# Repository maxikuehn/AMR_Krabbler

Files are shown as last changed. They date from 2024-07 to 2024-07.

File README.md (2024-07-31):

<div align="right">
HSMA Logo
</div>

<div align="center">

<h1>Technische Optimierungen am vierbeinigen Krabbler</h1>






<h3>Autonome Mobile Roboter - SS 2024</h3>
<h4>Maximilian Kühn</h4>

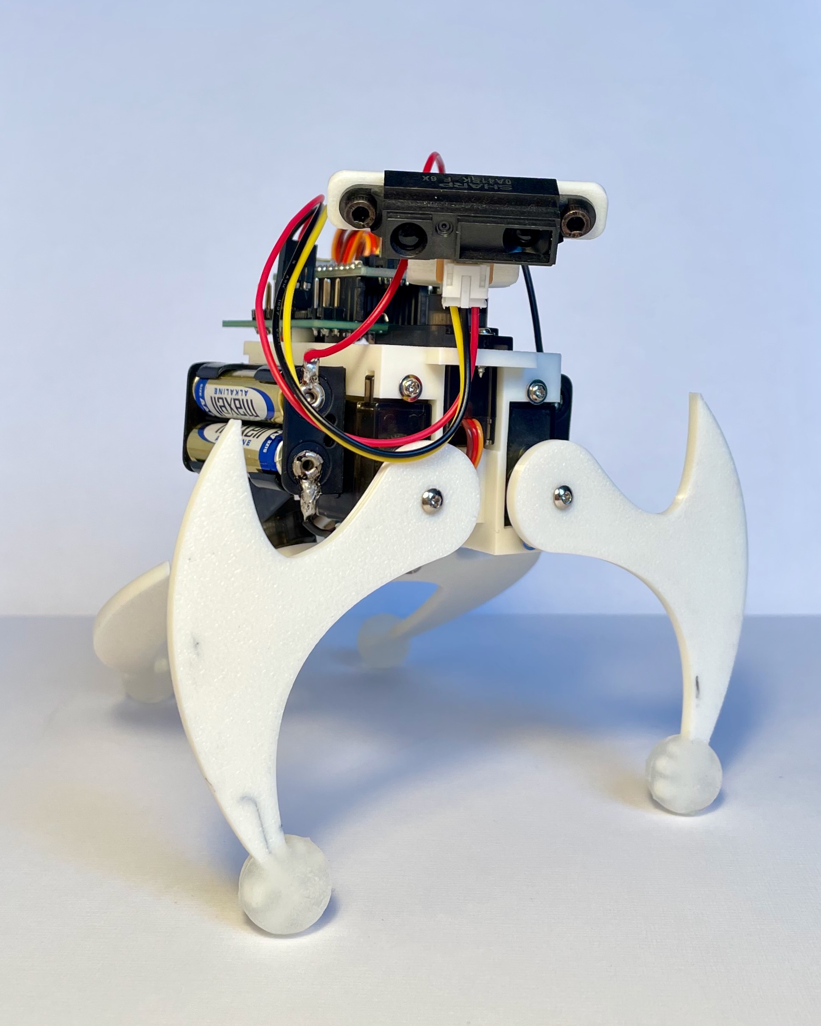
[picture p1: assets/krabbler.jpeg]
Krabbler


</div>

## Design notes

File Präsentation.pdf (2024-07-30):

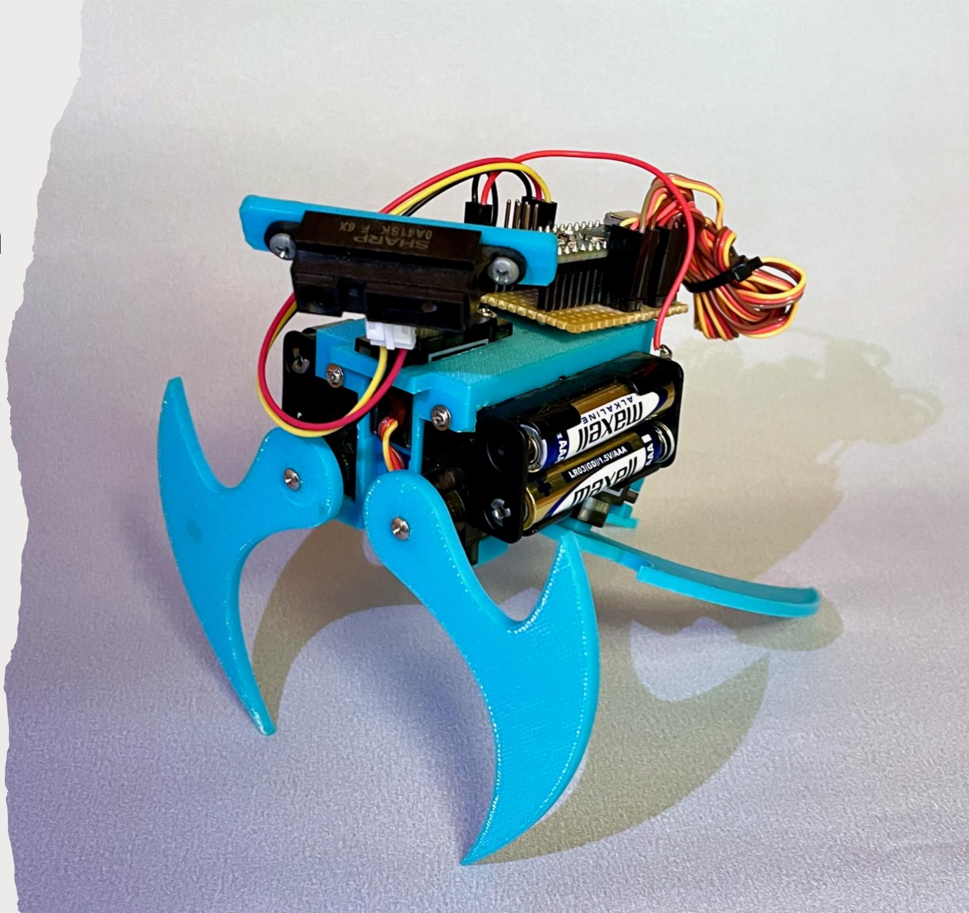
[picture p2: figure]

## Technische Optimierungen am vierbeinigen Krabbler

SS 24 – AMR
Maximilian Kühn

## Was ist der Krabbler

- simpler Roboter
- Arduino Nano
- 5 Servos
- Infrarotsensor
- Batterieversorgung
- 3D-Druck für die Teile

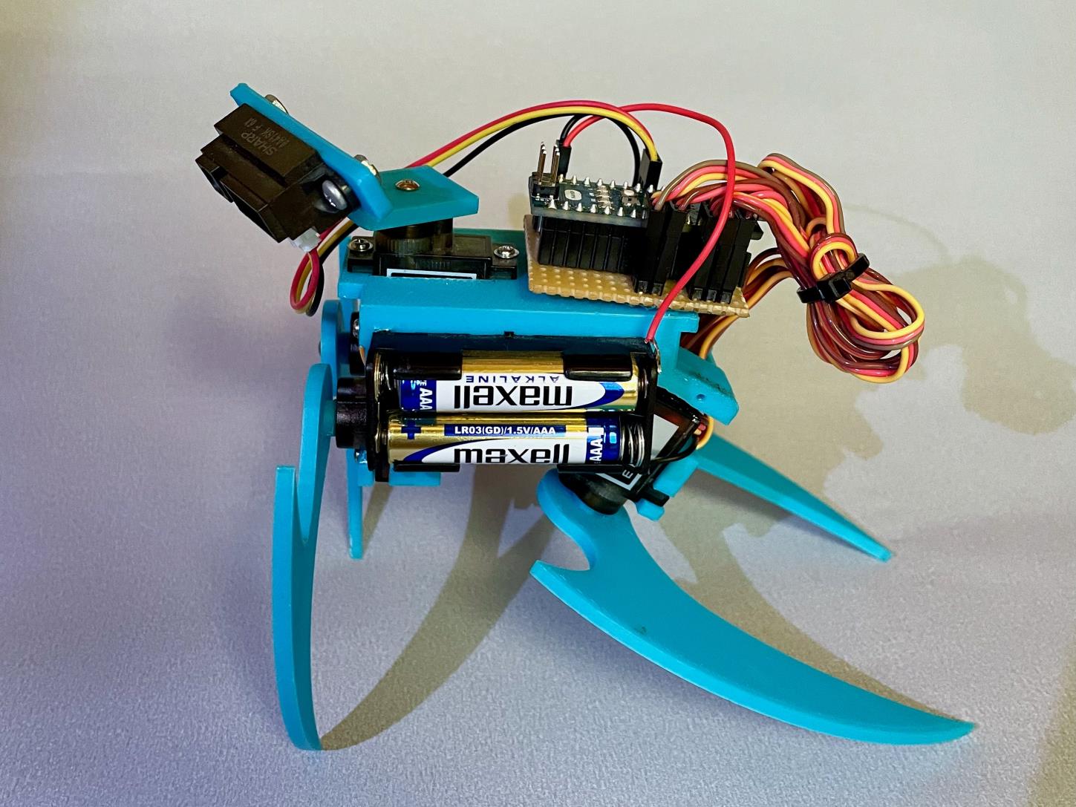
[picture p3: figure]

24.07.24 | Maximilian Kühn | 2

## Was ist an der Hardware nicht ideal?

- Platine
- Füße rutschen auf dem Tisch
- keine Möglichkeit ihn
auszuschalten
- 3D-Modelle nicht optimal

Version 2

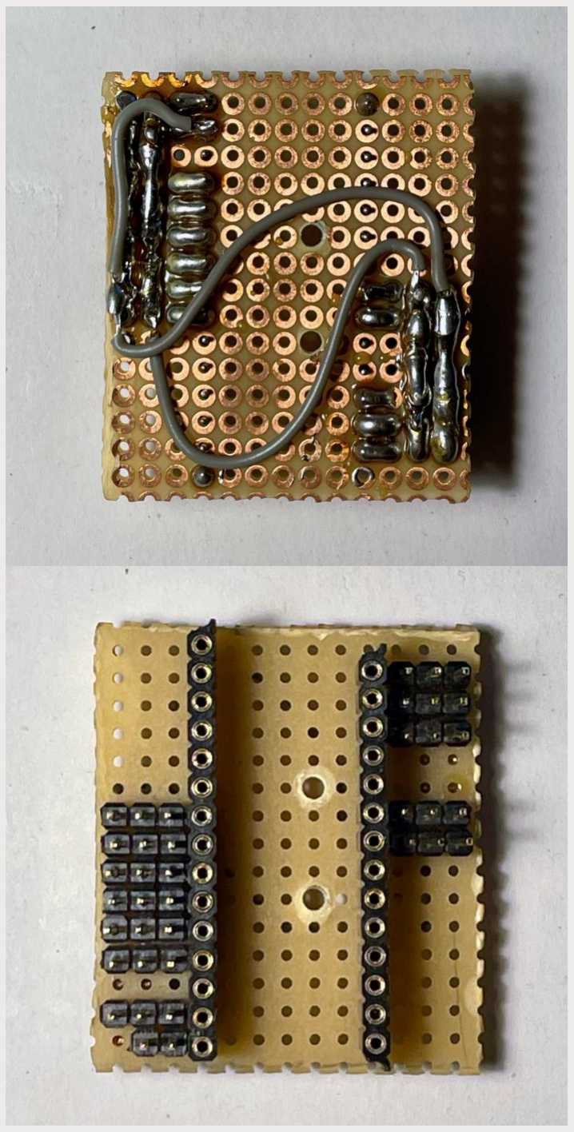
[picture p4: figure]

## Leiterplatte Version 1

alles von Hand gelötet
großer Zeitaufwand
fehleranfällig beim Löten
nicht intuitiv verwendbar

Version 2
✅ Unterstützung beim Löten ✅ intuitiv verwendbar
✅ kleiner Zeitaufwand

## Leiterplatte Version 2 Schaltplan

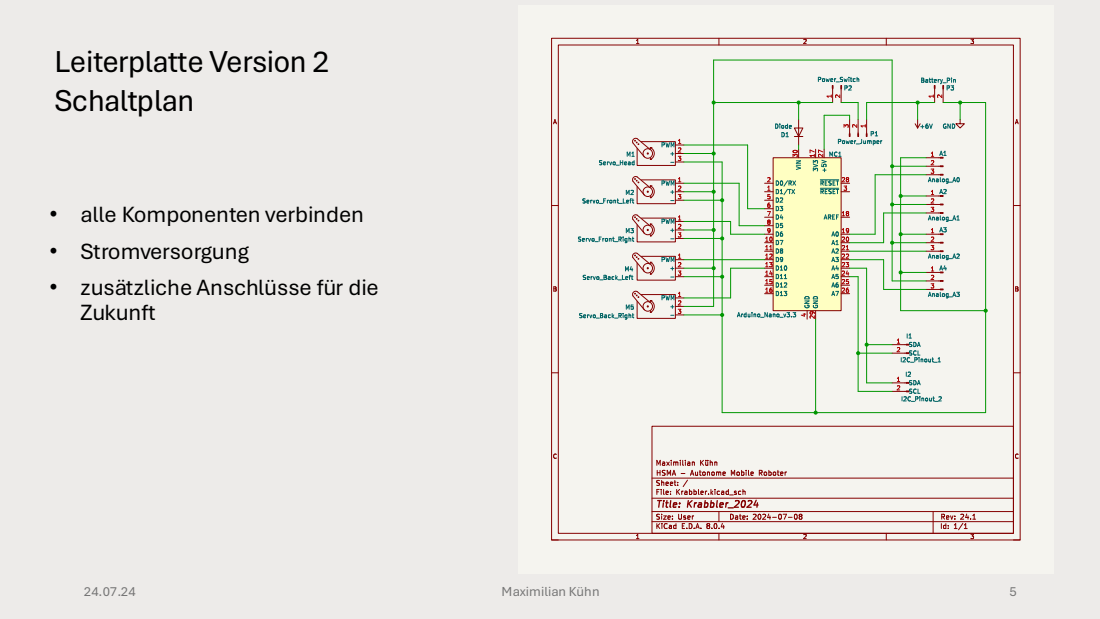
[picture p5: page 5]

• alle Komponenten verbinden
• Stromversorgung
• zusätzliche Anschlüsse für die
Zukunft

## Leiterplatte Version 2 Platine

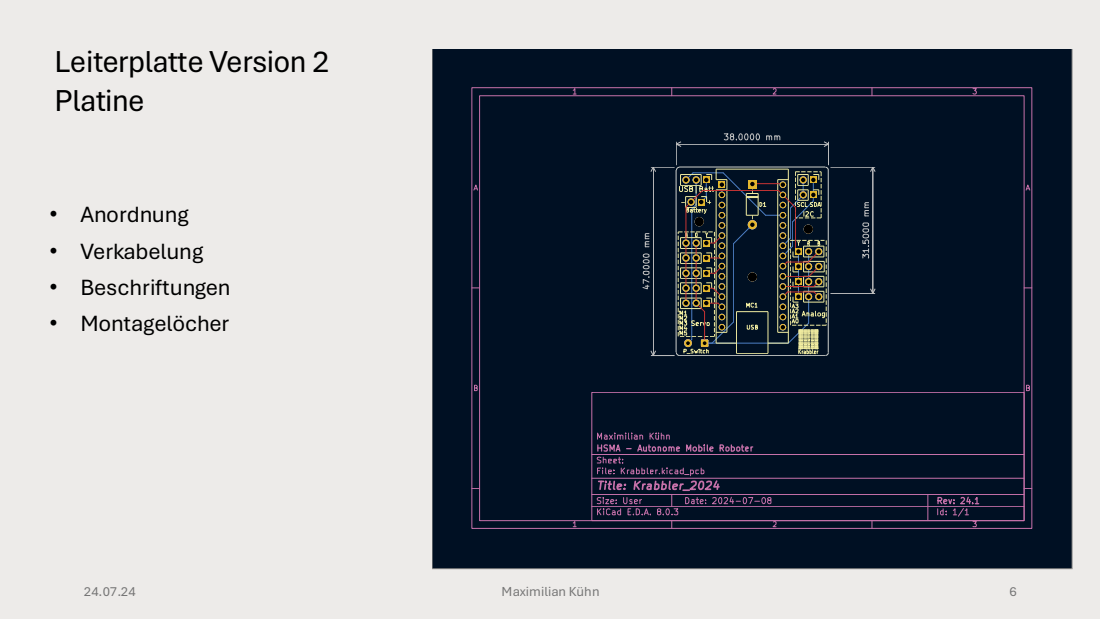
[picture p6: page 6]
• Anordnung • Verkabelung • Beschriftungen • Montagelöcher

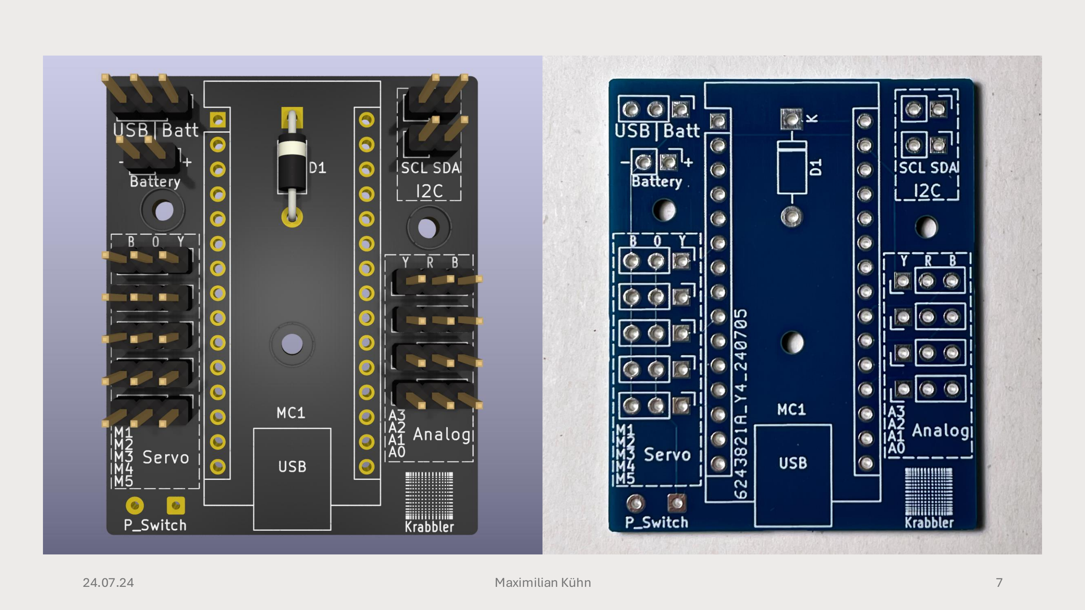
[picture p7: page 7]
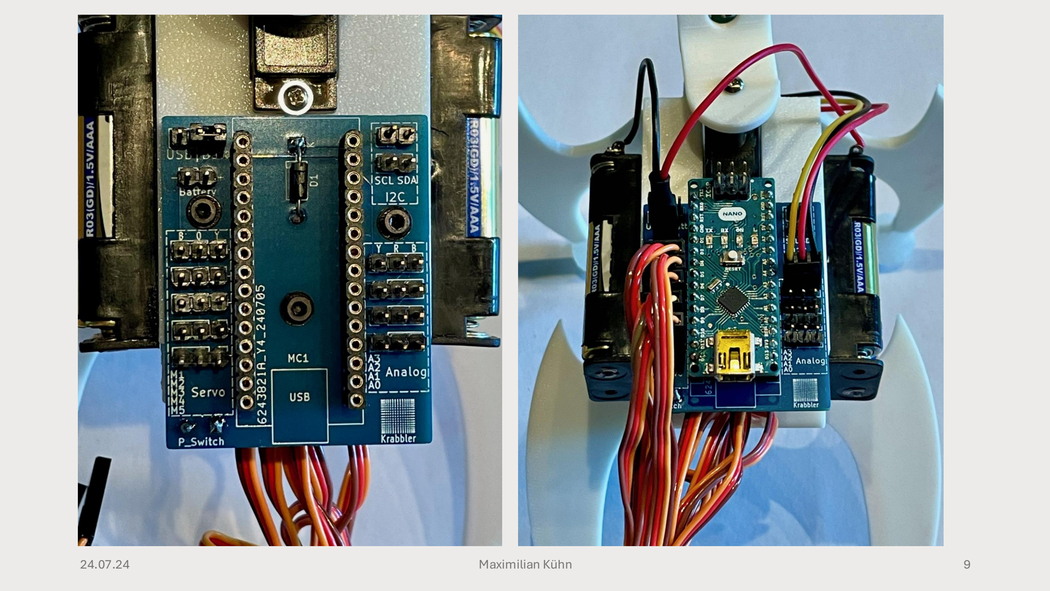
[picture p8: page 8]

## Füße Version 1

keine Haftung auf Tischen

3 Varianten
- Silikon
- TPU
- Haushaltsgummi

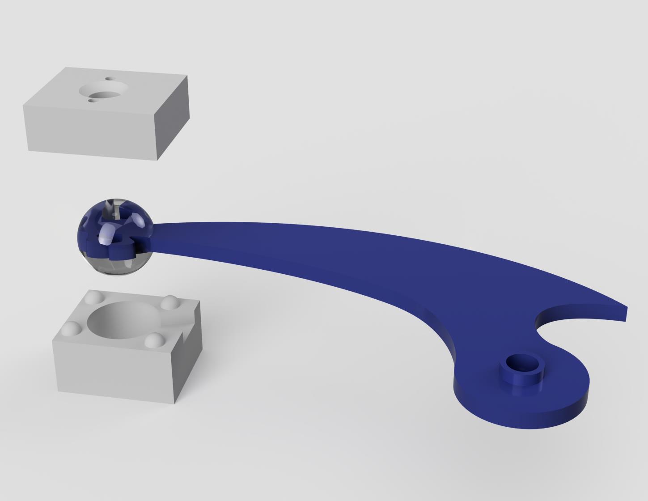
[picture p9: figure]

## Füße Version 2 Silikon

- Gussform
- Fußspitze mit Widerhaken

Silikon: RTV2 33 ShA

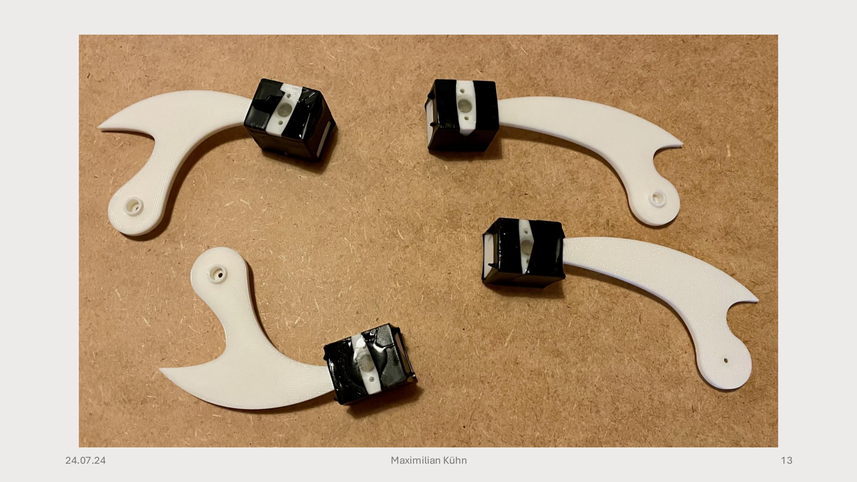
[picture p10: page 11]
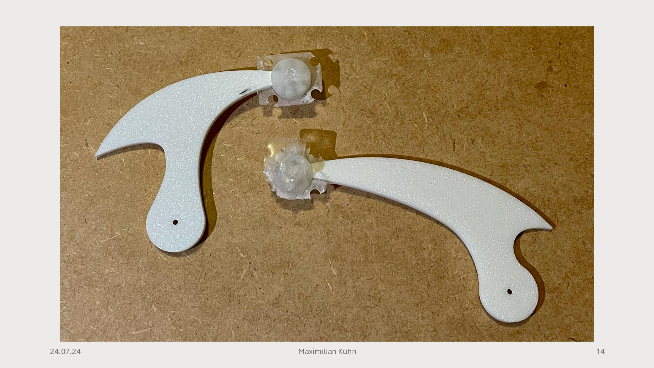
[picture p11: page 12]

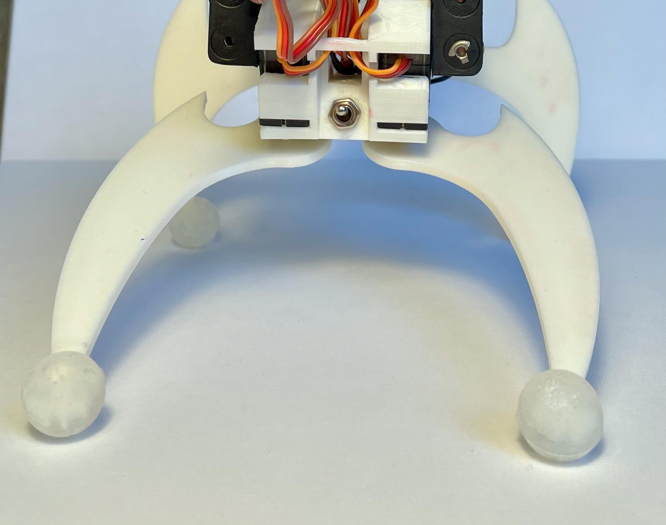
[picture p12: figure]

## Füße Version 2 Silikon

nicht kompliziert aber zeitintensiv

Aussehen der Füße deutlich verändert

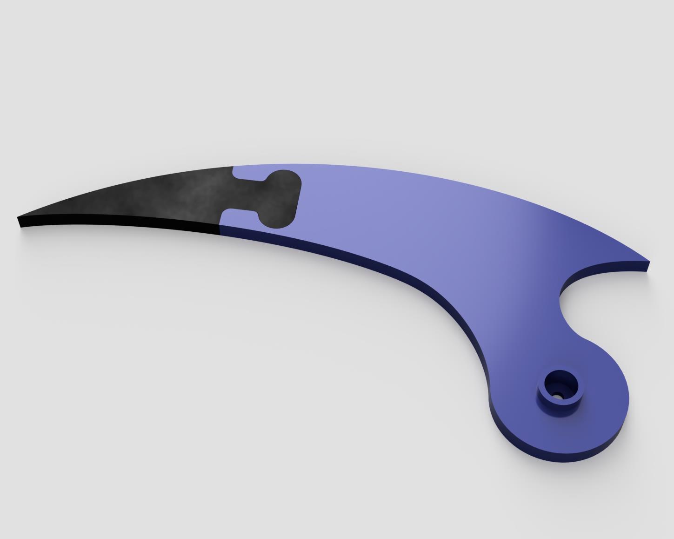
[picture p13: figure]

## Füße Version 2 TPU

- Spitze mit TPU drucken
- 95 ShA

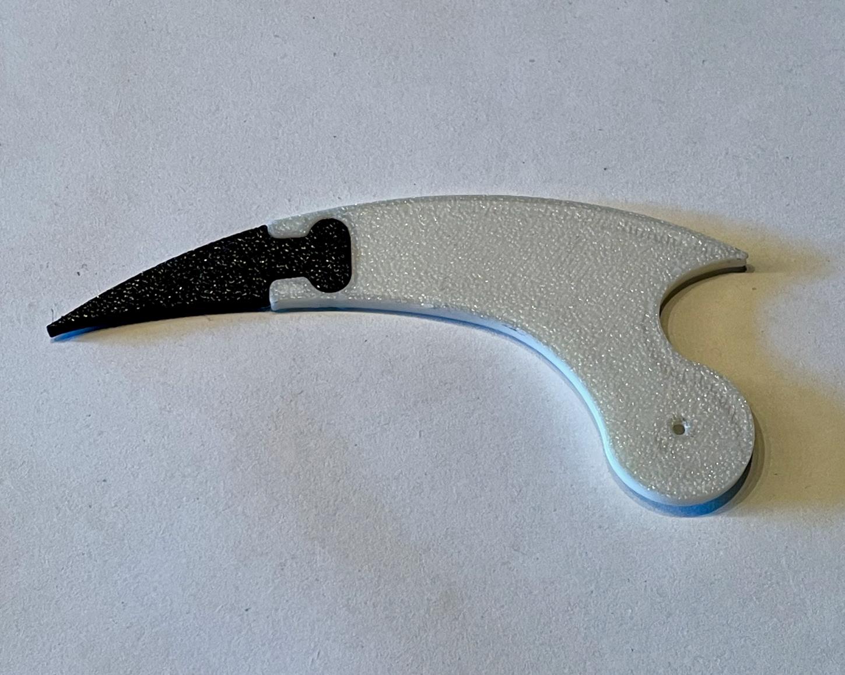
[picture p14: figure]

## Füße Version 2 TPU

schwer zu drucken
Spitze instabil
Puzzle-Verbindung reicht nicht aus

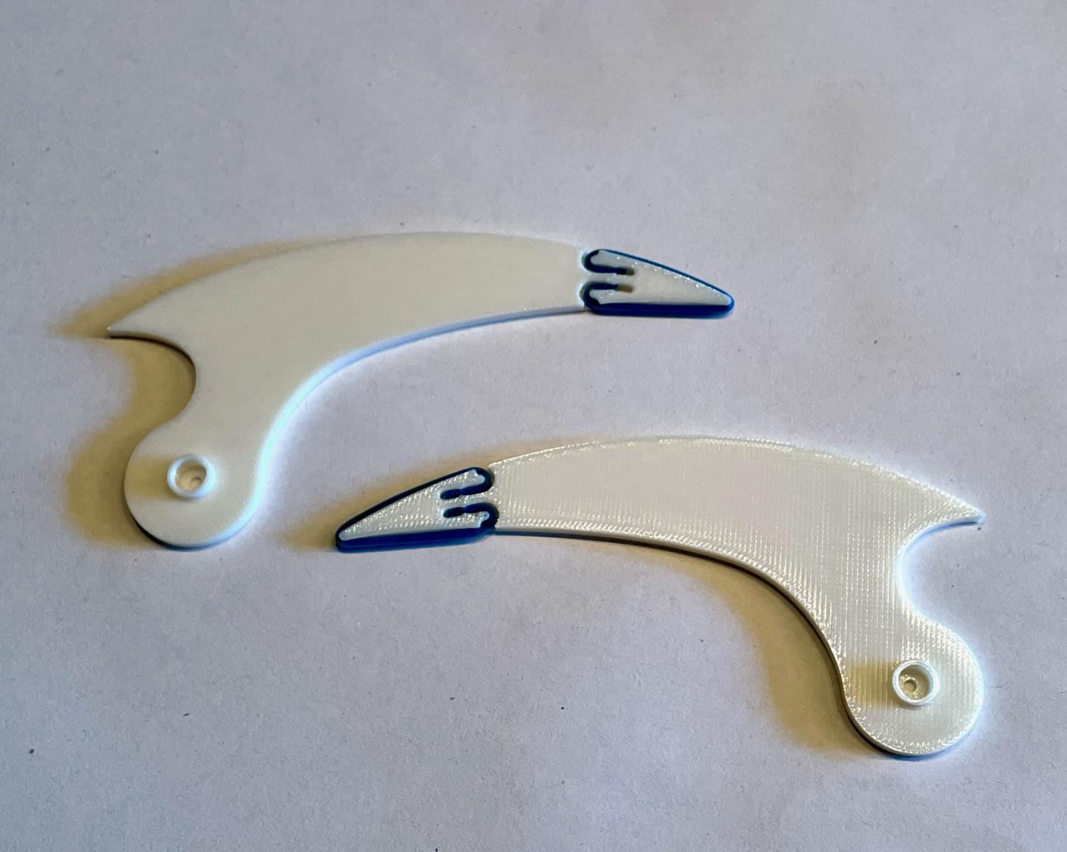
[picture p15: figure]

## Füße Version 2 Haushaltsgummi

- Haushaltsgummi um die Spitze spannen

keine Lösung für die Hinterbeine

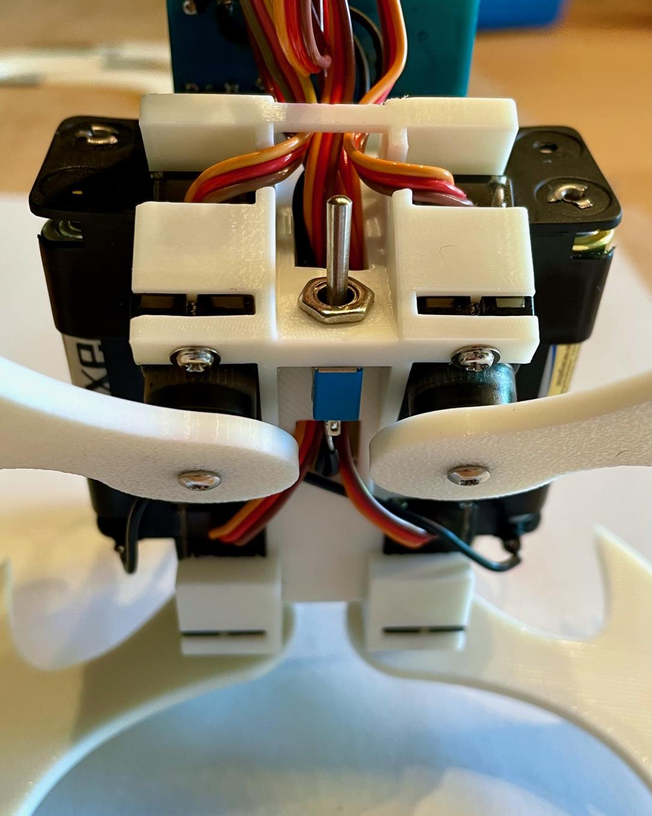
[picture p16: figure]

## Ein-/ Aus-Schalter

- Anschluss auf der Platine
- passender Platz auf dem Körper

## Verbessertes 3D-Modell

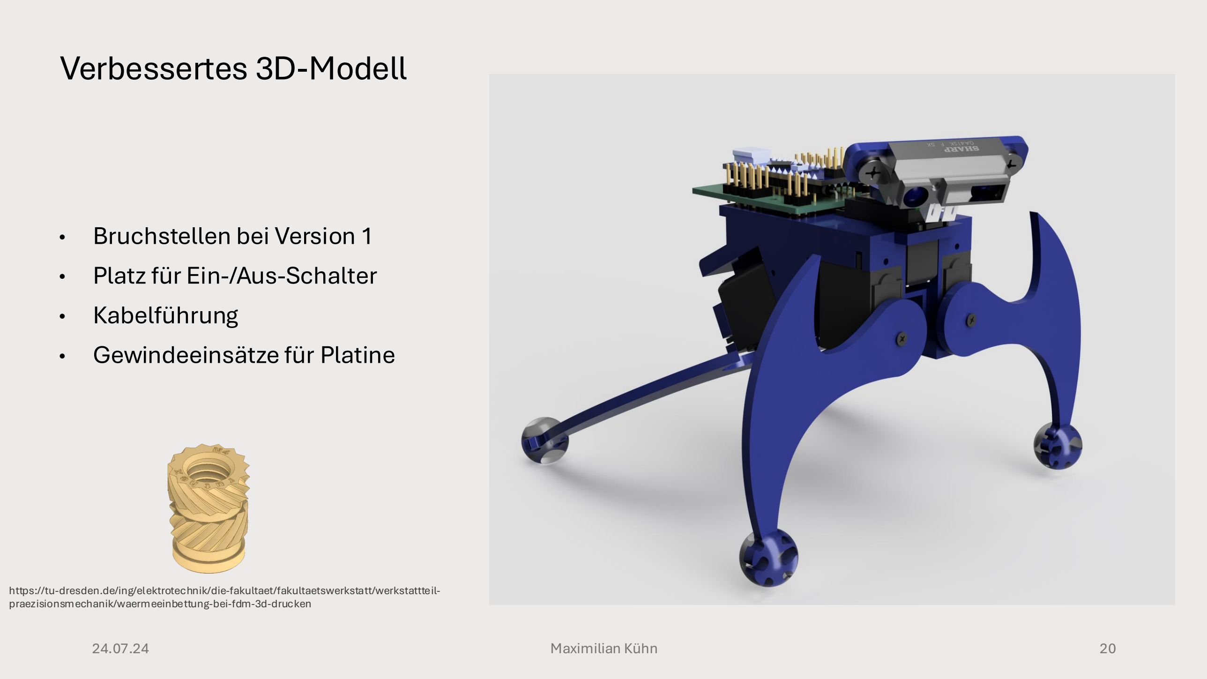
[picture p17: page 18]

- Bruchstellen bei Version 1
- Platz für Ein-/Aus-Schalter
- Kabelführung
- Gewindeeinsätze für Platine

https://tu-dresden.de/ing/elektrotechnik/die-fakultaet/fakultaetswerkstatt/werkstattteil-praezisionsmechanik/waermeeinbettung-bei-fdm-3d-drucken

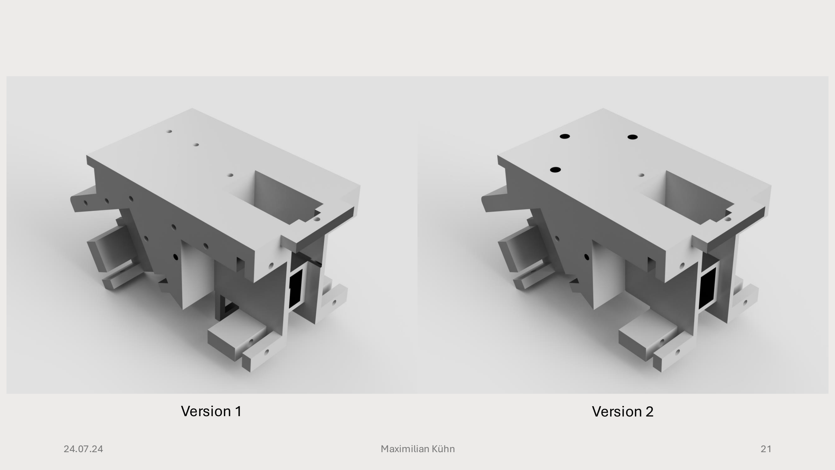
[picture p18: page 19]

Version 1 | Version 2

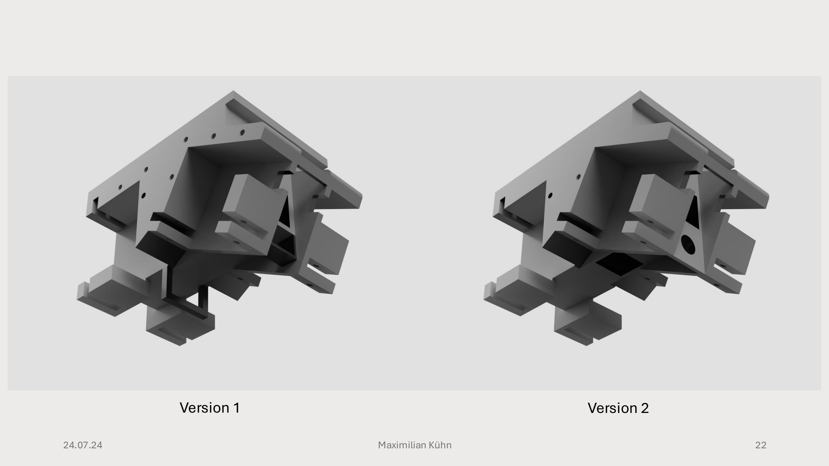
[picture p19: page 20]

Version 1 | Version 2

## Krabbler Version 2

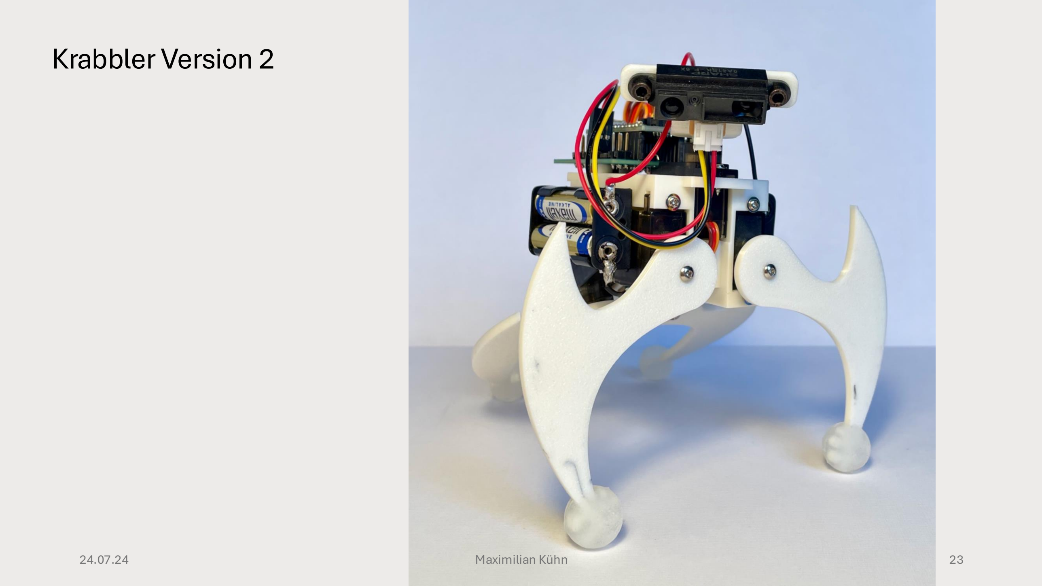
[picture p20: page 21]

# Danke!

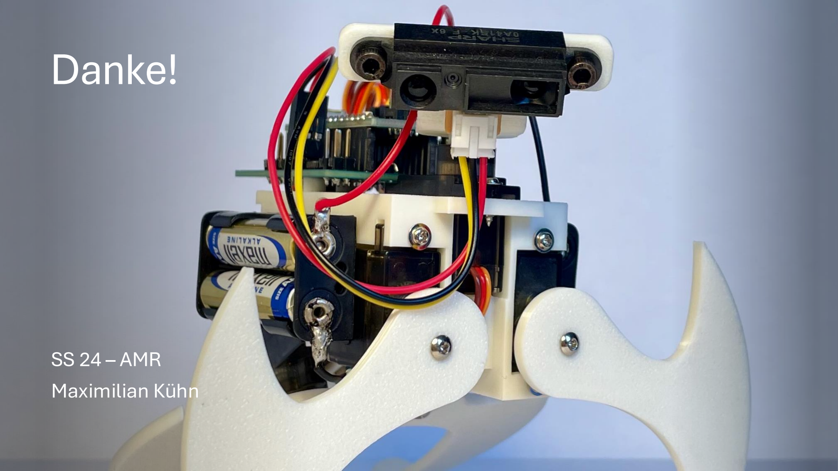
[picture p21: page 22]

### SS 24 – AMR Maximilian Kühn

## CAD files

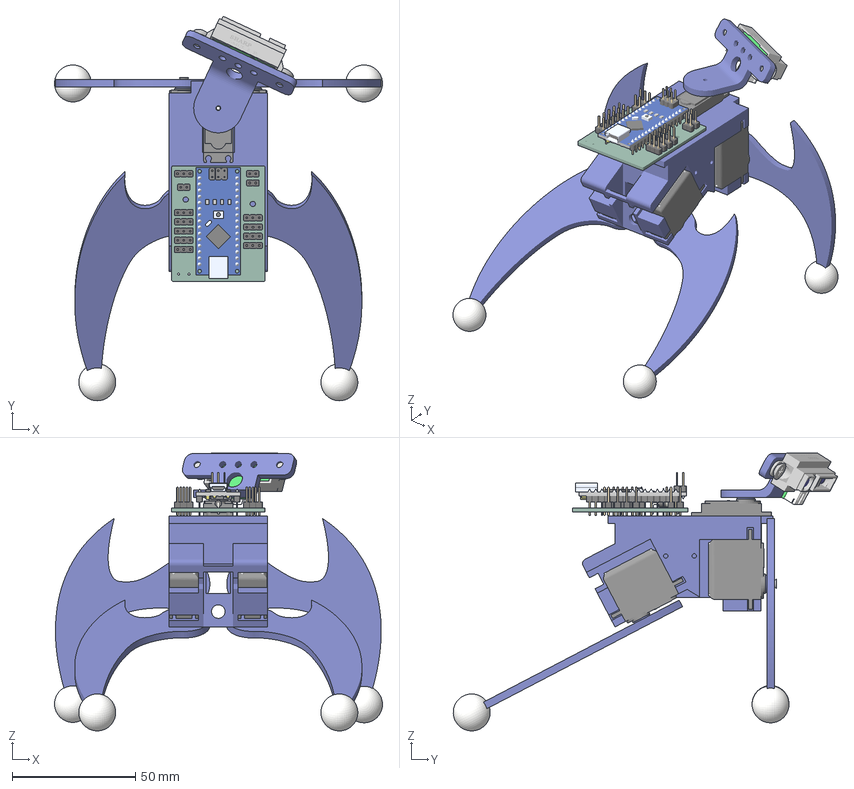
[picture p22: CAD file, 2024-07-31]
CAD/assembly.3mf
133.2 x 156.1 x 112.8 mm
Körper1 x 29
Körper2
Körper3
Silikonkugel x 4
back_leg x 2

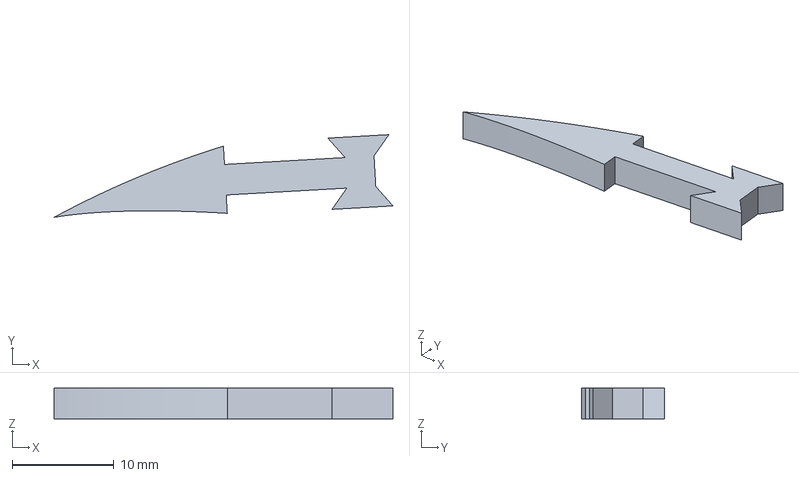
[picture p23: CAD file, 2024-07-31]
CAD/back_leg_left_tpu_v2_tip.3mf
33.2 x 8.11 x 3.00 mm

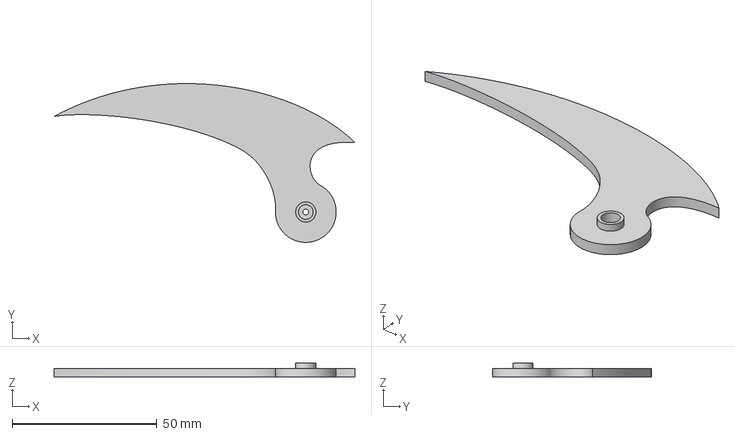
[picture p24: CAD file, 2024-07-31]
CAD/back_leg_left.3mf
104.0 x 54.9 x 5.00 mm

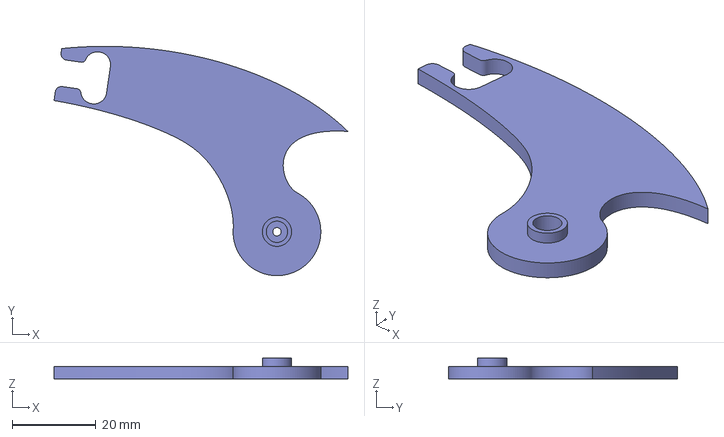
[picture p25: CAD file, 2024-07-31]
CAD/back_leg_left_tpu_base.3mf
70.4 x 54.9 x 5.00 mm

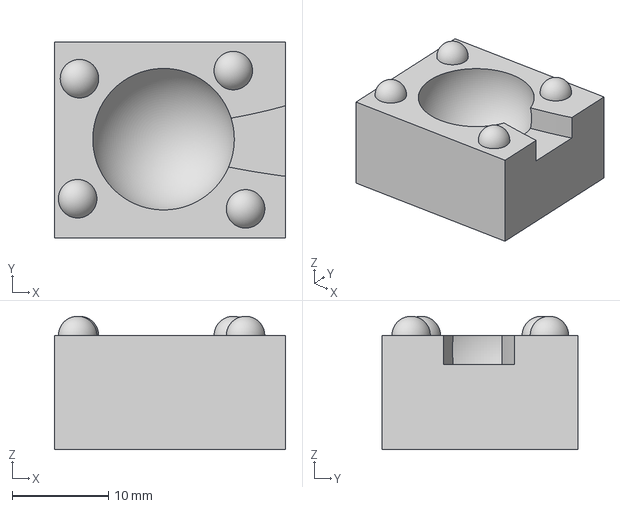
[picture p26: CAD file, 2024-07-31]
CAD/front_leg_silikongussform_bottom.3mf
24.0 x 20.4 x 13.9 mm

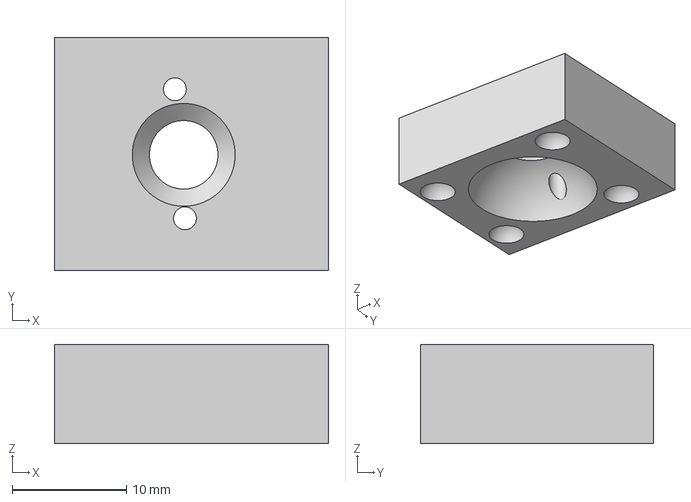
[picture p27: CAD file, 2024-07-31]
CAD/front_leg_silikongussform_top.3mf
24.0 x 20.4 x 8.69 mm

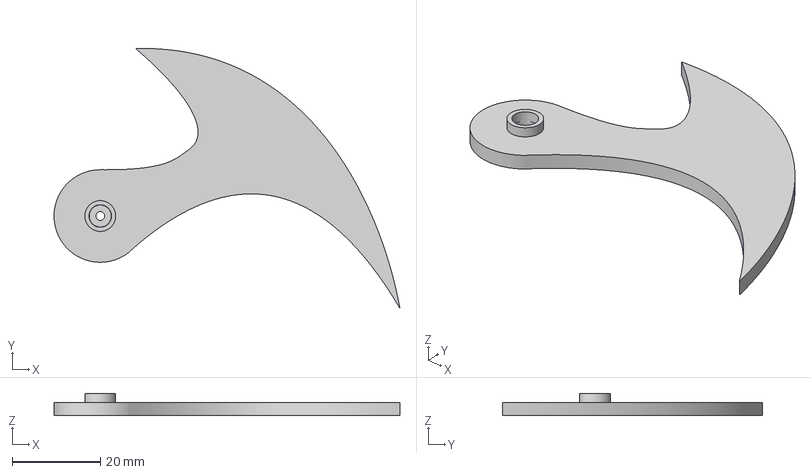
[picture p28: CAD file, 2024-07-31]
CAD/front_leg_right.3mf
78.5 x 59.0 x 5.00 mm

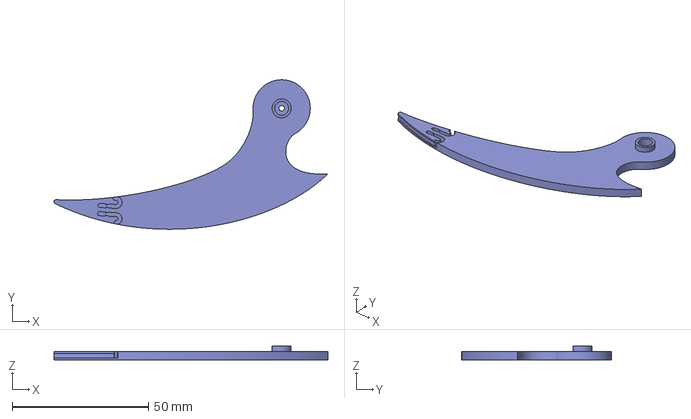
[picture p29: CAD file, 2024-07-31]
CAD/back_leg_left_gummiband.3mf
100.5 x 54.9 x 5.00 mm

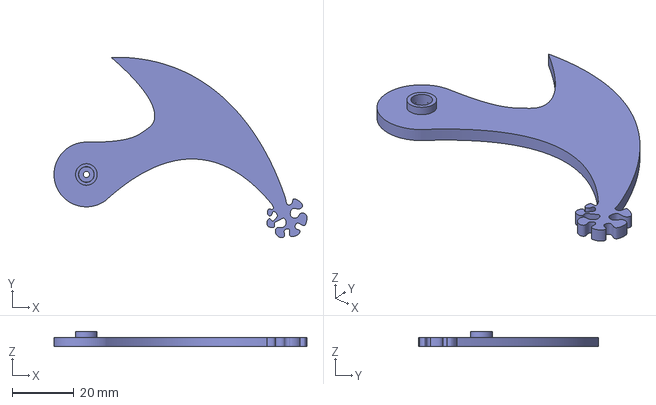
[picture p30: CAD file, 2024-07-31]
CAD/front_leg_right_silikonguss.3mf
82.1 x 58.5 x 5.00 mm

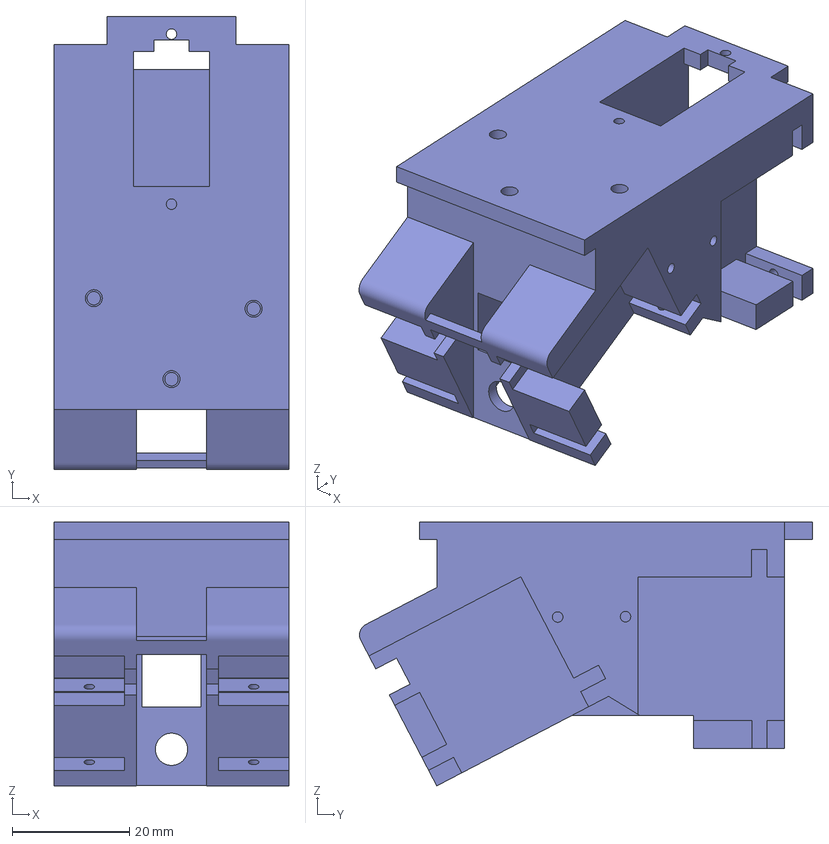
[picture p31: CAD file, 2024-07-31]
CAD/body.3mf
40.0 x 77.3 x 45.0 mm

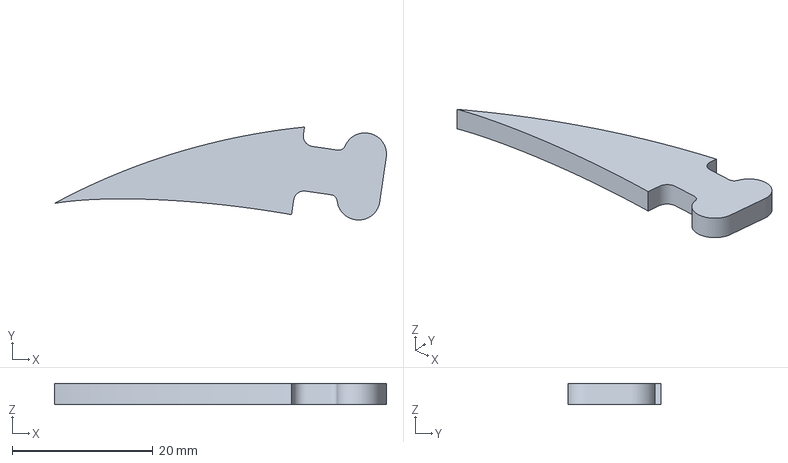
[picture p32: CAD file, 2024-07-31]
CAD/back_leg_left_tpu_tip.3mf
47.1 x 13.2 x 3.00 mm

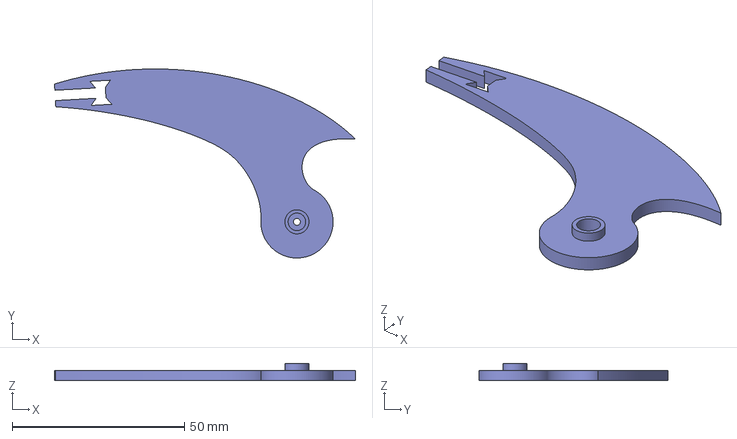
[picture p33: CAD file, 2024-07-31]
CAD/back_leg_left_tpu_v2_base.3mf
87.4 x 54.9 x 5.00 mm

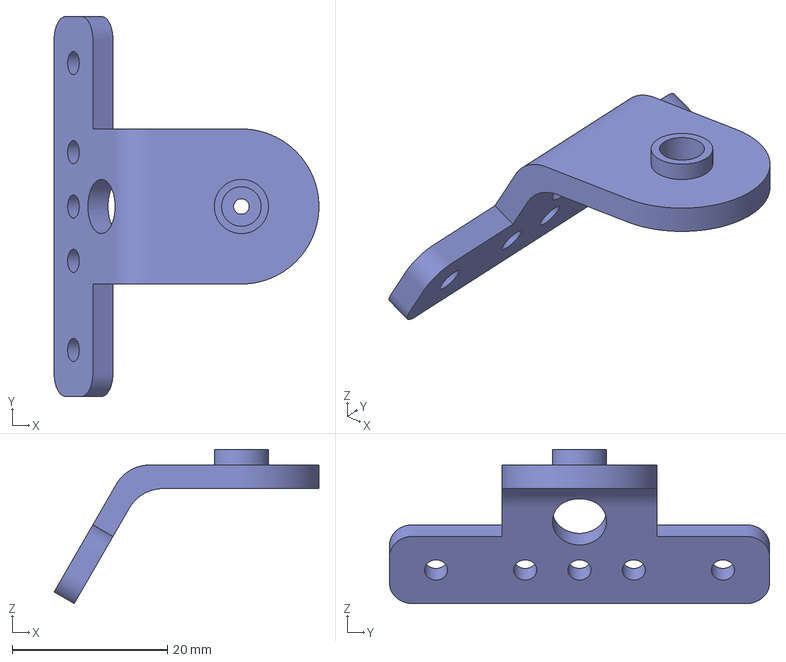
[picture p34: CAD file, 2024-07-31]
CAD/head.3mf
34.2 x 49.0 x 19.9 mm

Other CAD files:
CAD/back_leg_silikongussform_bottom.3mf
CAD/back_leg_left_silikonguss.3mf
CAD/back_leg_silikongussform_top.3mf

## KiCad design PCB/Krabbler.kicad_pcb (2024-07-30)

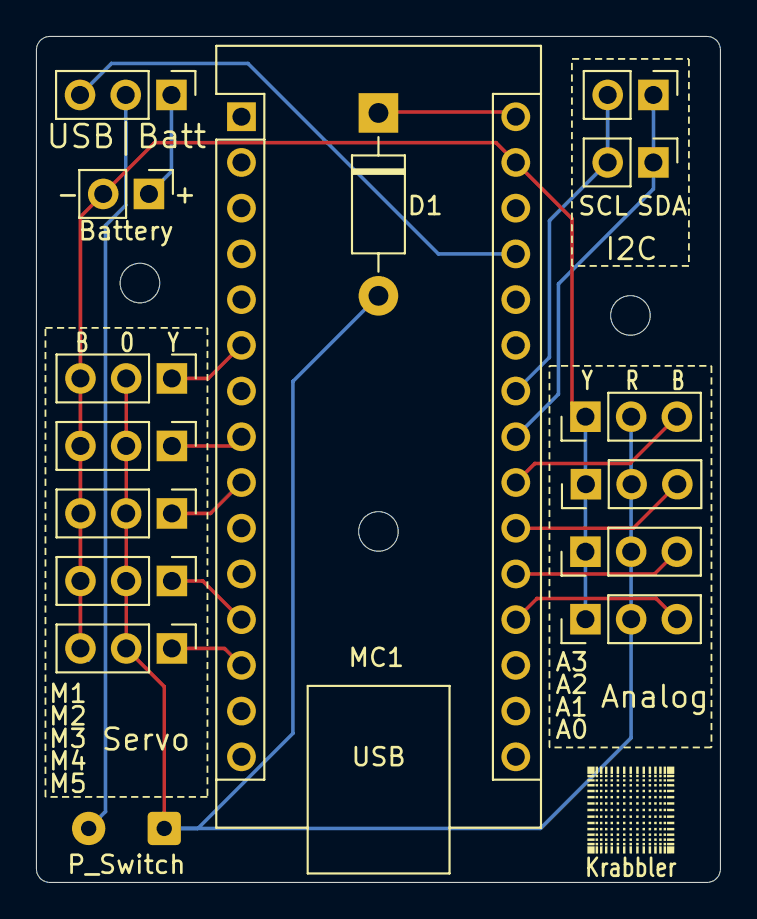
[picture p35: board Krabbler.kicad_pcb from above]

Board: 2 copper layers, 38.0 x 47.0 mm, 16 parts (0 on the bottom side), 16 nets.

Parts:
A1: Analog_A0; PinHeader_1x03_P2.54mm_Vertical
A2: Analog_A1; PinHeader_1x03_P2.54mm_Vertical
A3: Analog_A2; PinHeader_1x03_P2.54mm_Vertical
A4: Analog_A3; PinHeader_1x03_P2.54mm_Vertical
D1: Diode; D_DO-41_SOD81_P10.16mm_Horizontal
I1: I2C_Pinout_1; PinHeader_1x02_P2.54mm_Vertical
I2: I2C_Pinout_2; PinHeader_1x02_P2.54mm_Vertical
M1: Servo_Head; PinHeader_1x03_P2.54mm_Vertical
M2: Servo_Front_Left; PinHeader_1x03_P2.54mm_Vertical
M3: Servo_Front_Right; PinHeader_1x03_P2.54mm_Vertical
M4: Servo_Back_Left; PinHeader_1x03_P2.54mm_Vertical
M5: Servo_Back_Right; PinHeader_1x03_P2.54mm_Vertical
MC1: Arduino_Nano_v3.3; Arduino_Nano
P1: Power_Jumper; PinHeader_1x03_P2.54mm_Vertical
P2: Power_Switch; SolderWire-0.25sqmm_1x02_P4.2mm_D0.65mm_OD1.7mm
P3: Battery_Pin; PinHeader_1x02_P2.54mm_Vertical

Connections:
+6V: P1.1 (-), P3.1
unnamed: A1.2 (+), A2.2 (+), A3.2 (+), A4.2 (+), D1.2 (A), M1.2 (+), M2.2 (+), M3.2 (+), M4.2 (+), M5.2 (+), P2.1
unnamed: A1.1 (-), A2.1 (-), A3.1 (-), A4.1 (-), M1.3 (-), M2.3 (-), M3.3 (-), M4.3 (-), M5.3 (-), MC1.29 (GND), P3.2
unnamed: A1.3 (data), MC1.19 (A0)
unnamed: A2.3 (data), MC1.20 (A1)
unnamed: A3.3 (data), MC1.21 (A2)
unnamed: A4.3 (data), MC1.22 (A3)
unnamed: D1.1 (K), MC1.30 (VIN)
unnamed: I1.1 (SDA), I2.1 (SDA), MC1.23 (A4)
unnamed: M1.1 (PWM), MC1.6 (D3)
unnamed: M2.1 (PWM), MC1.8 (D5)
unnamed: M3.1 (PWM), MC1.9 (D6)
unnamed: M4.1 (PWM), MC1.12 (D9)
unnamed: M5.1 (PWM), MC1.13 (D10)
unnamed: MC1.27 (+5V), P1.3 (data)
unnamed: P1.2 (+), P2.2

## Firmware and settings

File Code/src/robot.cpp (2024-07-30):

#include "Arduino.h"

#include <Servo.h>
#include <math.h>

Servo leftFrontLegServo;
Servo rightFrontLegServo;
Servo headServo;
Servo leftBackLegServo;
Servo rightBackLegServo;
int pos1, pos2, pos3, pos4, pos5;

int get_distance(int analogInput)
{
  float volts = 0;
  if (analogInput == 3)
  {
    volts = analogRead(A3) * 0.0048828125; // value from sensor * (5/1024)
  }
  else if (analogInput == 4)
  {
    volts = analogRead(A4) * 0.0048828125; // value from sensor * (5/1024)
  }
  else if (analogInput == 5)
  {
    volts = analogRead(A5) * 0.0048828125; // value from sensor * (5/1024)
  }
  else if (analogInput == 6)
  {
    volts = analogRead(A6) * 0.0048828125; // value from sensor * (5/1024)
  }
  else if (analogInput == 7)
  {
    volts = analogRead(A7) * 0.0048828125; // value from sensor * (5/1024)
  }

  int distance = 13 * pow(volts, -1); // worked out from datasheet graph
  return distance;
}

double counter;
void setup()
{
  // initialize digital pin LED_BUILTIN as an output.
  pinMode(LED_BUILTIN, OUTPUT);

  pos1 = 40;  // bein links vorne
  pos2 = 90;  // bein rechts vorne
  pos3 = 60;  // kopf
  pos4 = 40;  // bein links hinten
  pos5 = 140; // bein rechts hinten

  leftFrontLegServo.attach(11);
  rightFrontLegServo.attach(10);
  headServo.attach(9);
  leftBackLegServo.attach(6);
  rightBackLegServo.attach(5);

  counter = 0;
}

void loop()
{
  double angle1 = 20 * sin(counter);
  double angle2 = 20 * cos(counter);

  leftFrontLegServo.write(pos1 + angle1);
  rightFrontLegServo.write(pos2 + angle1);
  headServo.write(pos3 + angle1);
  leftBackLegServo.write(pos4 + angle2);
  rightBackLegServo.write(pos5 + angle2);

  counter = counter + 0.002;
}
